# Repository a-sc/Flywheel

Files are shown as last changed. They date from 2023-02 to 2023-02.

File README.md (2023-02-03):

# Exploring flywheel energy storage with a DIY prototype

This repository contains design files and documentation for a DIY flywheel
energy storage system. It is part of my
[maturité](https://en.wikipedia.org/wiki/Matura) project on mechanical
batteries. If you want to know more about it, visit the
[website](https://a-sc.github.io/Flywheel), which is automatically generated
from the contents of the `docs` folder.

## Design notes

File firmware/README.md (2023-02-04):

# Firmware for the NUCLEO-F401RE board

The code in this directory is graciously provided by Tomasz Włostowski. He
developed it in the context of another flywheel project (based on a brushless DC
motor he scraped off a hard drive). I adapted it slightly to work on my
home-made motor, notably adjusting the proportional gain in the PI controller
and working on the sequencing of the phases to be able to turn my flywheel both
clockwise and anticlockwise. In any case, the heavy lifting was done by Tom, so
kudos to him.

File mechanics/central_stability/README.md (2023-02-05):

# 3D models used for centering of the flywheel

Here are the three 3D models used to build the centering system of the flywheel. The adapter plate is inserted into where the head of the tripod originally was, and fixed in place with the nut. Then, magnets are aligned from the bottom plate to the top plate using a screw and a spacer, as well as a nut to close it. If you want to know more about it, visit the [website](https://a-sc.github.io/Flywheel).

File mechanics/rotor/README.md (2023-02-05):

# 3D model used for rotor

The rotor consists of this 3D model printed twice and stuck together with superglue. If you want to know more about it, visit the [website](https://a-sc.github.io/Flywheel).

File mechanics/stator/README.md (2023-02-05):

# 3D models used for the stator

There are 3 coils in this stator, each made up of one 3D printed coil plate and coil shaft. These two pieces are inserted together without adhesive, and the coil is spun around the shaft by hand until the wire reaches the edge of the plate. The central part of the stator is used to provide support for the point of the rod. It is designed to fit right into the middle of the stator body, which has two sets of 3 towers equidistant to the center. The closer towers are where the hall sensors are placed, whilst the furthest towers house the coils. If you want to know more about it, visit the [website](https://a-sc.github.io/Flywheel).

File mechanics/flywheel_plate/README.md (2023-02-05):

# Flywheel plate mechanics

The flywheel plate design I am using is an earlier version of the one contained
in this directory, unfortunately not available anymore because it was done
before the design went into version control. The original author of the design
is Tomasz Włostowski, and he not only allowed me to post the files here but also
gave me a prototype of the plate made with his CNC machine. 

Although not a PCB, the mechanical design is actually a
[KiCad](https://www.kicad.org/) project, using only the PCB layout part of the
tool (i.e. no schematics). You will need KiCad 7 or later to open it. If you are
curious about its shape but not enough to install KiCad, here it is for your
viewing pleasure:

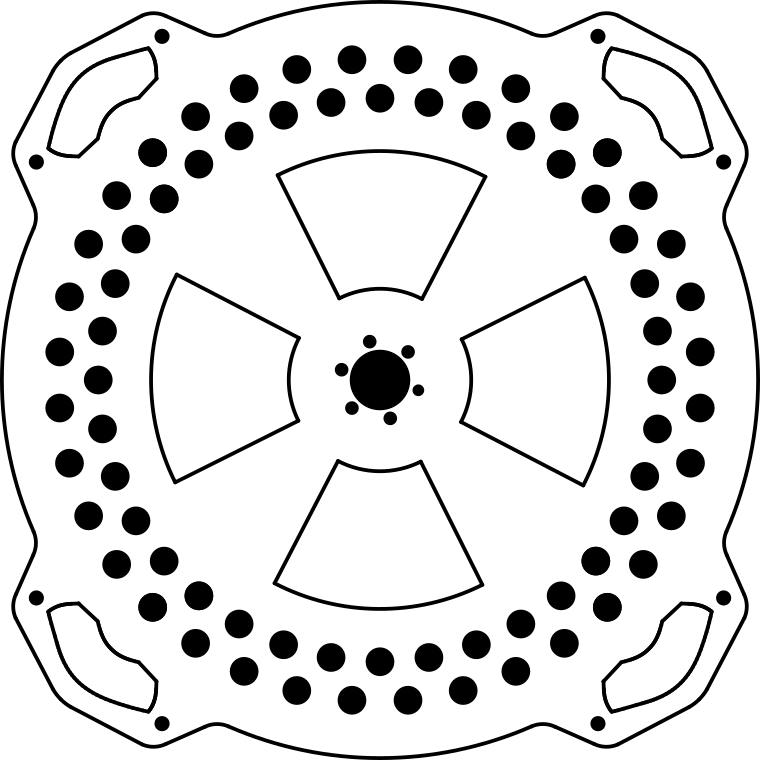
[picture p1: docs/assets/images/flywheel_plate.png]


The holes in the periphery allow increasing the moment of inertia (and hence the
stored energy for a given rotational speed) by adding nuts and bolts all around
the flywheel.

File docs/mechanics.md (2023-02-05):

---
layout: page
title: Mechanics
permalink: /mechanics/
---

* Dummy list
{:toc}

## Key concepts

The project is built around a [Manfrotto compact action tripod](https://www.manfrotto.com/us-en/compact-action-aluminium-tripod-with-hybrid-head-black-mkcompactacn-bk/) that will be used as the support for the rest of the build. The head of the tripod is removed, and an m8 threaded stainless steel rod around 450mm long is passed through the hole in the middle of the tripod. In terms of magnets, two different kinds are used: 9 [more powerful, larger magnets](https://www.magnetiques.fr/magnetique,aimant-brut-torique-19-1mm-x-9-5mm-x-6-4mm.html) and 32 [smaller and less powerful kind.](https://www.magnetiques.fr/magnetique,aimant-brut-torique-10mm-x-5mm-x-5mm.html) Both are neodymium ring magnets.

The flywheel rod is vertical. Its weight is supported by a sharpened point end, and its alignment is ensured by a magnetic centering system. The rotor is attached to the rod, towards the bottom, and the stator is on the ground directly below the rod. The flywheel is a few centimeters above the rotor.

Starting from the bottom, the project needs a moveable flat surface to facilitate alignment of different parts of the flywheel. In this case, I used a [circular wooden plate](https://www.amazon.fr/Planche-d%C3%A9couper-ronde-circulaire-double/dp/B07V1NTN4Q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), but any flat surface of similar dimensions works. The tripod will be placed on top of this surface in a fully opened position.

## Stator

On top of the base goes the stator. It is almost entirely 3D printed, and all the 3D models can be found [here](https://github.com/a-sc/Flywheel/tree/main/mechanics/stator). A [large m8 stainless steel washer](https://www.amazon.fr/Rondelles-Carrosserie-Inoxydable-Carrossier-ext%C3%A9rieur/dp/B0B6BS663W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) with an outer diameter of anywhere from 25-40mm is stuck to the bottom of the "Stator central part" model.

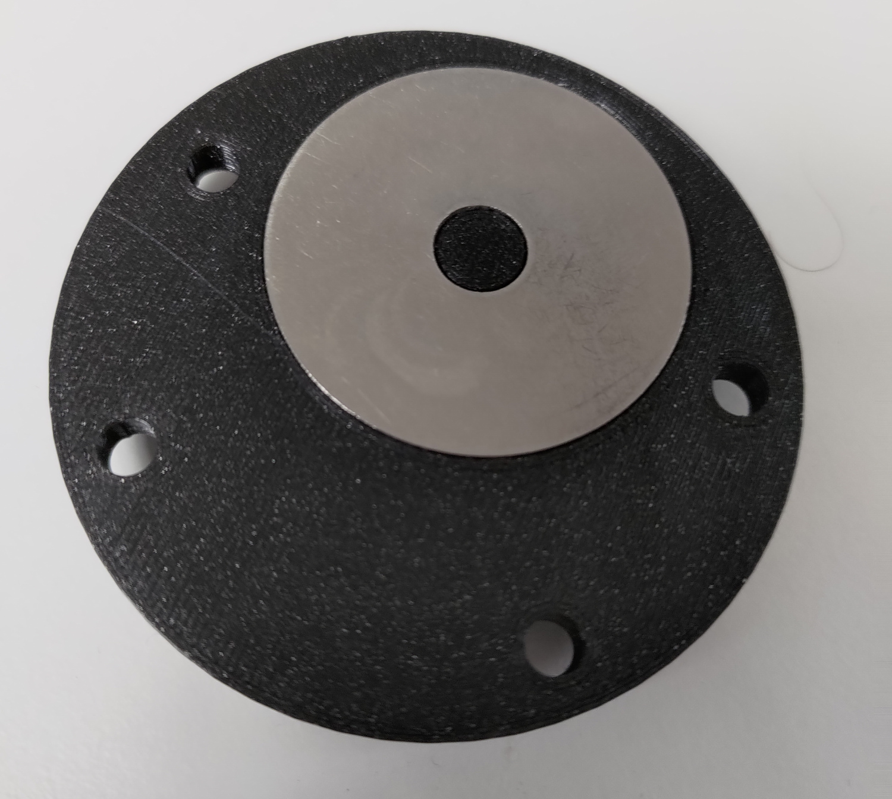
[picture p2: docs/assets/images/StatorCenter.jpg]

*Underside of the stator central part*

This is where the point of the rod will spin. This part is placed in the middle of the wooden plate, and around it goes the "Stator body".

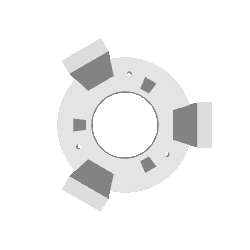
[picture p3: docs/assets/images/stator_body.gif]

*The stator body 3D model*

This part consists of 2 sets of 3 towers equidistant from the center. The 3 hall sensors are placed on the smaller towers of the stator body. 3 coils are made using the "Coil plate" and "Coil shaft" parts. This is done by inserting these two parts together without using adhesive, and wrapping 0.25mm diameter copper wire around the coil shaft until the wire comes up to the edge of the coil plate. To finish the coils, I recommend adding epoxy to the wire to stop it from moving. These 3 coils are then attached to the 3 taller towers of the stator's body. For sticking both the coils and the hall sensors to the stator's body, I used double sided tape as this gave me the most flexibility, but any adhesive works.

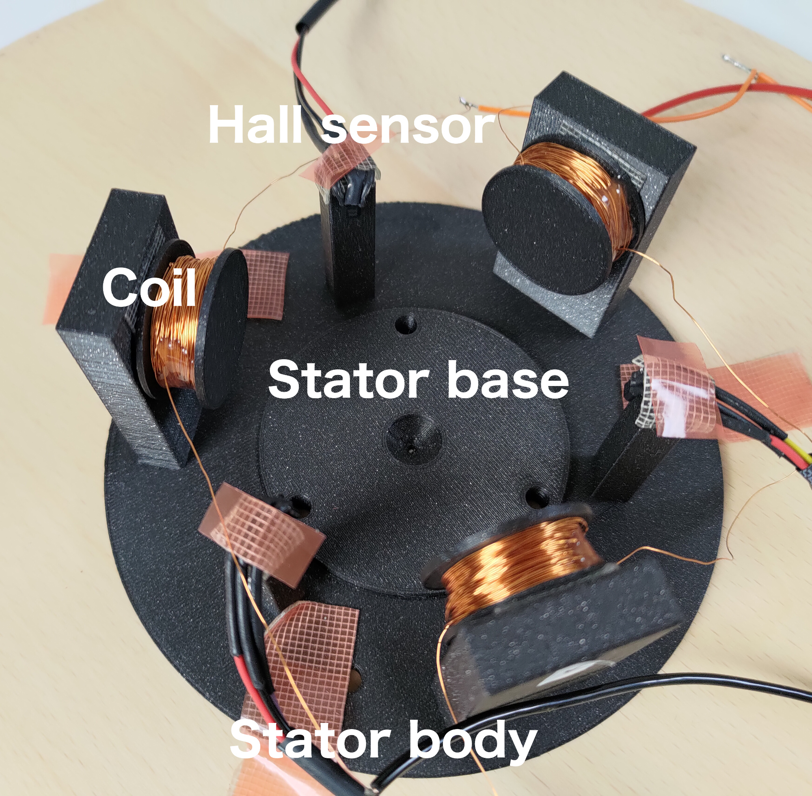
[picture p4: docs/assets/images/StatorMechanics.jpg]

*Fully assembled stator*

## Rotor and flywheel

On the rod, at the same level as the stator, is the rotor. The 3D model can be found [here](https://github.com/a-sc/Flywheel/tree/main/mechanics/rotor). The 3D model is only half of the rotor, so it has to be printed twice and stuck together with something like superglue. 

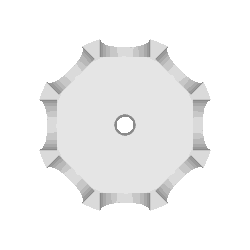
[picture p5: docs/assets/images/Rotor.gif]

*The rotor 3D model*

The rotor has 8 holes in which to put magnets. The more powerful magnets are used, and have to be placed in alternating polarities (north/south/north/south).

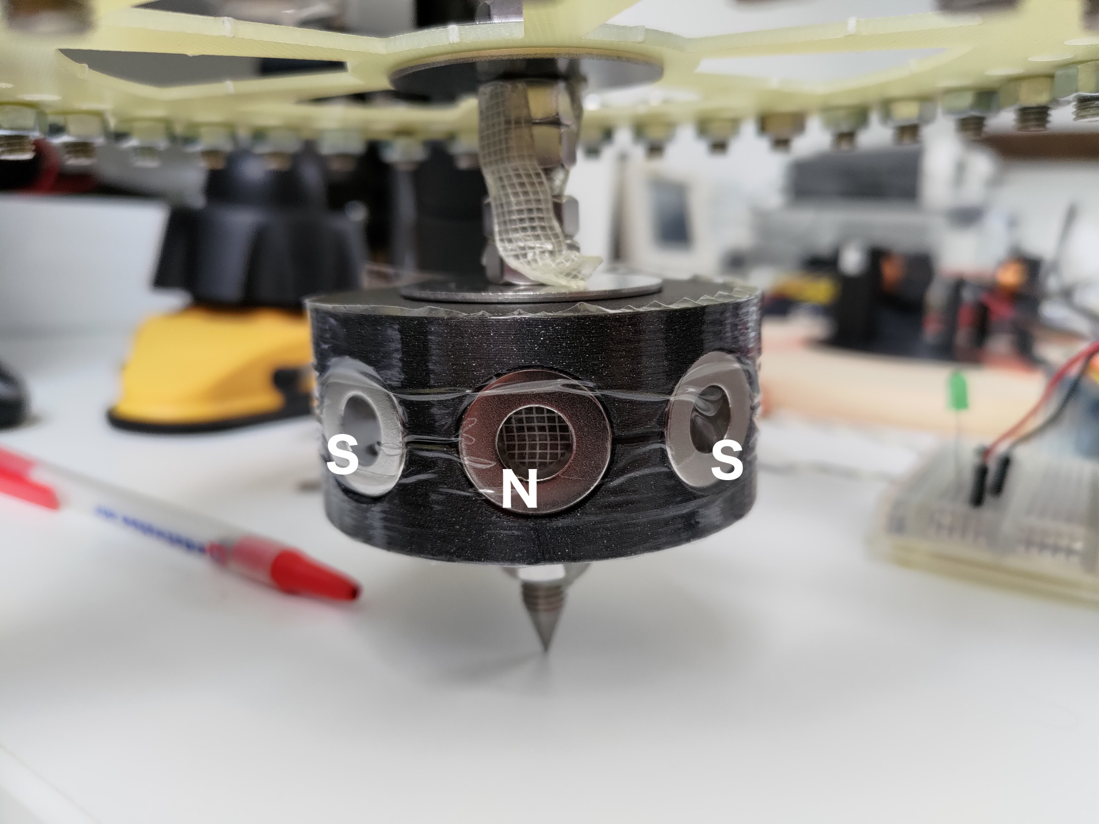
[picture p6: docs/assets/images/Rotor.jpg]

*Rotor on the threaded rod*

The flywheel that I used is a [relatively thin fiberglass disc with a radius of around 10cm](https://github.com/a-sc/Flywheel/tree/main/mechanics/flywheel_plate) and is placed slightly above the rotor. Screws are added around the outside of the flywheel to increase the moment of inertia, and the flywheel is inserted into the steel tube and fixed in place with nuts. 

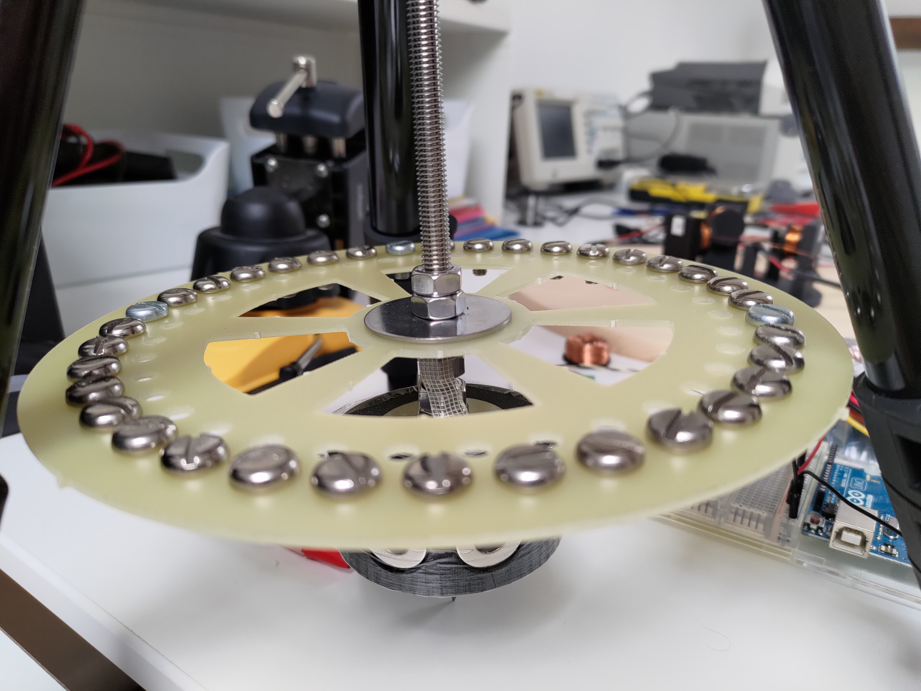
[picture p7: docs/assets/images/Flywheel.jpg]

*The flywheel I used*

In reality, any homogenous disc that fits the m8 threaded rod more or less well can be used. It does, however, need to fit inside of the tripod legs, so the diameter cannot be too large.

## Threaded rod

The threaded rod serves a few purposes: firstly, it aligns the different parts of the build vertically thanks to nuts. It also supports the weight of the build. In order for the rod to have as little friction as possible, its end has to be sharpened to a point. There are two ways to do this: one is to glue a nut to a screw and thread the nut into the end, and the other is to machine the end of the rod into a sharp point. This point is then placed on the metal washer glued to the "Stator central part", since metal on metal leads to very minimal friction. I first used the method with the screw, and the stability was satisfactory but not perfect. I later machined the end of the rod into a sharp point and there is no longer any wobbling.

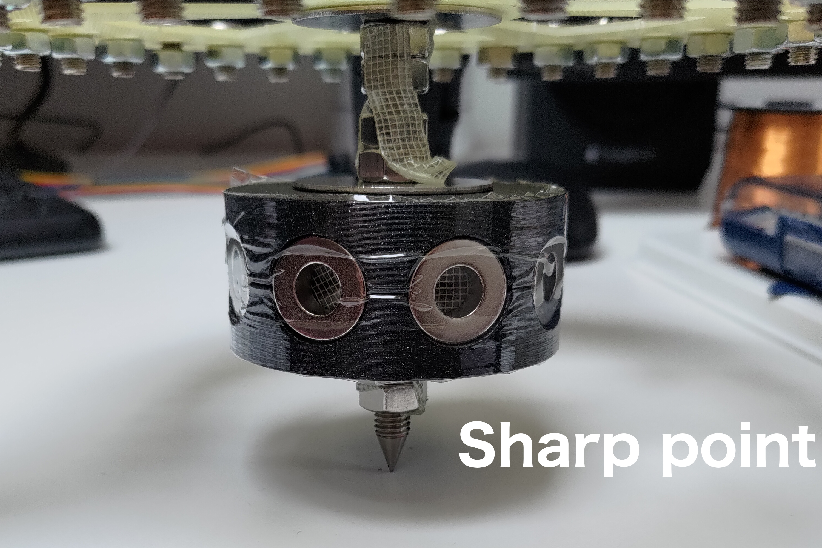
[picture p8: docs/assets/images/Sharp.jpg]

*Machined sharp point*

The third and last purpose of the rod is to align all the components horizontally, such that they are always perfectly perpendicular to the floor. The 3D models used to achieve horizontal stability can be found [here](https://github.com/a-sc/Flywheel/tree/main/mechanics/central_stability). The "tripod adapter" is inserted into the hole where the tripod head originally was, and it is held in place with the "nut tripod" object. 8 M4 stainless steel bolts are inserted into the outer holes of the "tripod adapter" from the bottom. Into each of these bolts goes a "spacer magnet" piece along with 4 small magnets. All of the magnets have to be aligned in the same direction. The end of the 8 bolts are entered into the "top plate" and fixed in place with nuts.

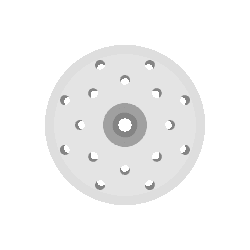
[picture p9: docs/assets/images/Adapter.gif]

*The tripod adapter 3D model*

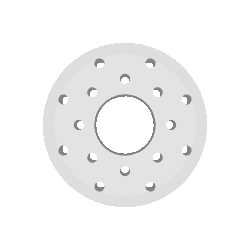
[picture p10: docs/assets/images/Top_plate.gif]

*The top plate 3D model* 

A large magnet is then added to the threaded rod in the same direction as the small magnets. Its vertical positioning should be such that it is inside the cylinder created by the smaller magnets, and slightly below the middle of the cylinder so that the vertical force is slightly downwards.

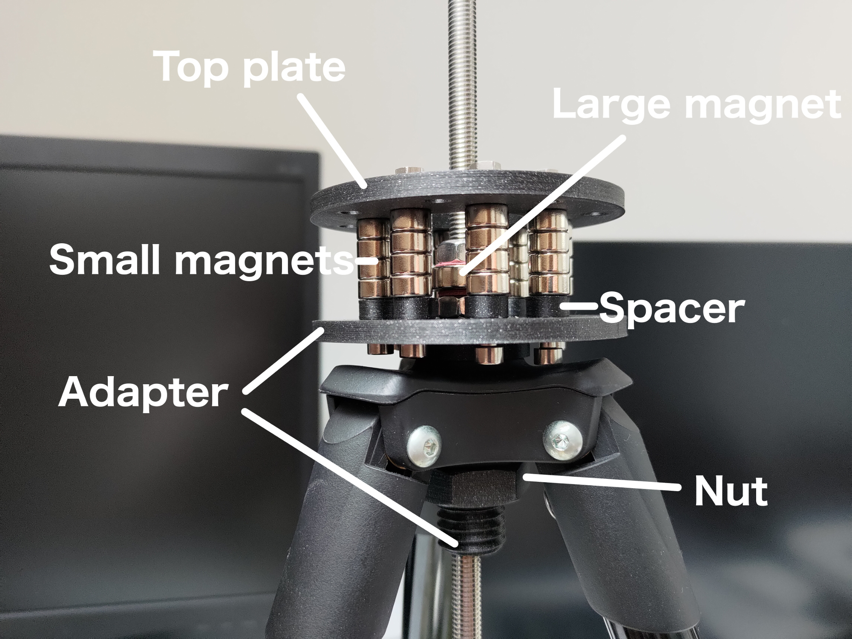
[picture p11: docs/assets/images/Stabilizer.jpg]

*Stabilizing complex*

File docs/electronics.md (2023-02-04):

---
layout: page
title: Electronics
permalink: /electronics/
---

The control of the home-made motor is pretty much like the control of any
brushless DC motor (BLDC). The main hardware components on the electronics side
are a [NUCLEO-F401RE](https://www.st.com/en/evaluation-tools/nucleo-f401re.html)
development board from ST, a [motor control
shield](https://www.infineon.com/cms/en/product/evaluation-boards/bldc-shield_ifx007t/)
by Infineon and a basic comparator circuit I put together to interface to the
Hall sensors.

* Dummy list
{:toc}

## STM32 Nucleo-64 development board

I selected this board because I could easily get hold of [BLDC control
code](https://github.com/a-sc/Flywheel/tree/main/firmware) for it. It features
an [STM32F401RE
MCU](https://www.st.com/en/microcontrollers-microprocessors/stm32f401re.html)
with 512 Kbytes of Flash memory and an 84 MHz CPU. The MCU contains all the
peripherals I need. In particular, a powerful set of timers to send pulse width
modulation (PWM) signals to the coils of the motor and measure its speed, plus
external general-purpose input/output (GPIO) pins I use to read Hall sensor
signals and have them produce interrupts.

## IFX007T motor shield

This PCB features three
[IFX007T](https://www.infineon.com/cms/en/product/power/motor-control-ics/brushed-dc-motor-driver-ics/single-half-bridge-ics/ifx007t/)
half-bridges. A half-bridge is half of what you need to make an
[H-bridge](https://en.wikipedia.org/wiki/H-bridge), which is what is typically
used to control motors. In essence, a half-bridge is made of two MOSFET
transistors connected in series. In my case, I connect the higher one to the
supply voltage (9V most of the time) and the lower one to ground. The output of
the half-bridge is the mid-point connection between the MOSFETs, so by
controlling them with the STM32 CPU I can connect the output either to ground or
to 9V.

During operation, I can drive a variable amount of current through a coil by
sending a PWM signal to the higher transistor of the corresponding H-bridge and
connecting the lower transistor (of the other half-bridge in the H-bridge) to
ground. The duty cycle of the PWM signal sets the average current through the
coil. The sense of the current depends on which half-bridge is used for,
respectively, PWM and ground, so can be easily changed by the MCU. See the
[firmware description](firmware.md) for more details.

## Interfacing with the Hall sensors

I use the [AH49E](https://www.diodes.com/part/view/AH49E/) Linear Hall-effect IC
from Diodes Incorporated for sensing the instantaneous position of the motor.
This is needed by the control firmware. The chips are conveniently available in a
TO-92S package which allowed me to solder their pins directly to flying wires and
keep full freedom in their physical placement. There are three Hall sensors in
the motor, interleaved at regular intervals with the three windings in the
stator. This means an angular separation of 120° between Hall sensors and 60°
between any Hall sensor and its closest coil either side.

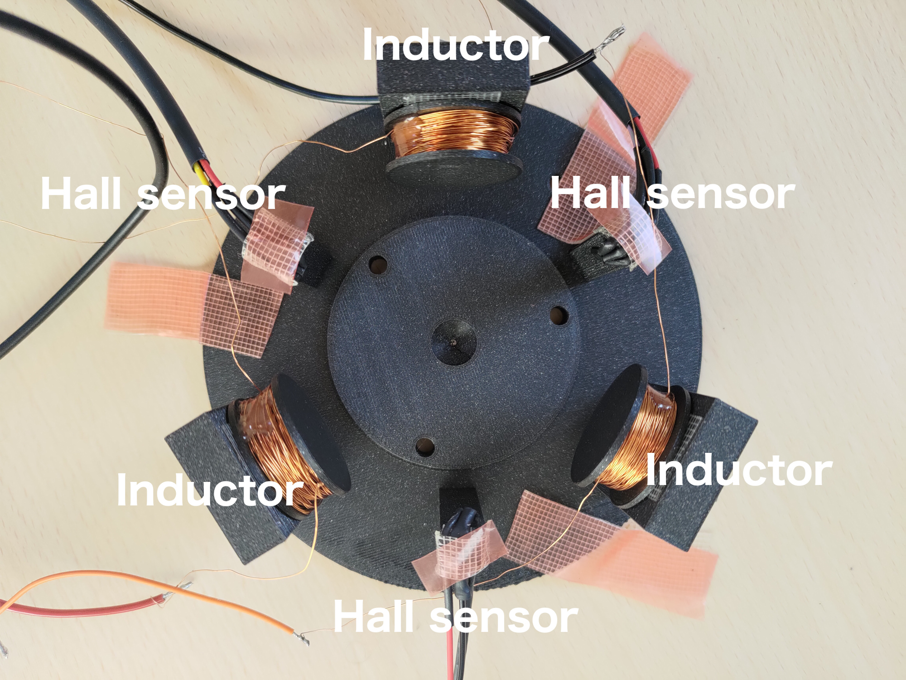
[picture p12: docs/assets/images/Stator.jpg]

*A close-up view of the placement of the Hall sensors in the stator*

The orientation of the Hall sensors is chosen to produce a negative-going signal
whenever the north pole of a permanent magnet in the rotor goes past them. The
output of the Hall sensor sits around half-way between ground and the positive
supply when not exposed to any field (the Earth field is much weaker than the
one produced by the magnets). In order to get a proper 0V or 3.3V signal I can
send to the MCU, I condition the signals coming from the sensors using a simple
LM339 comparator with a bit of hysteresis.

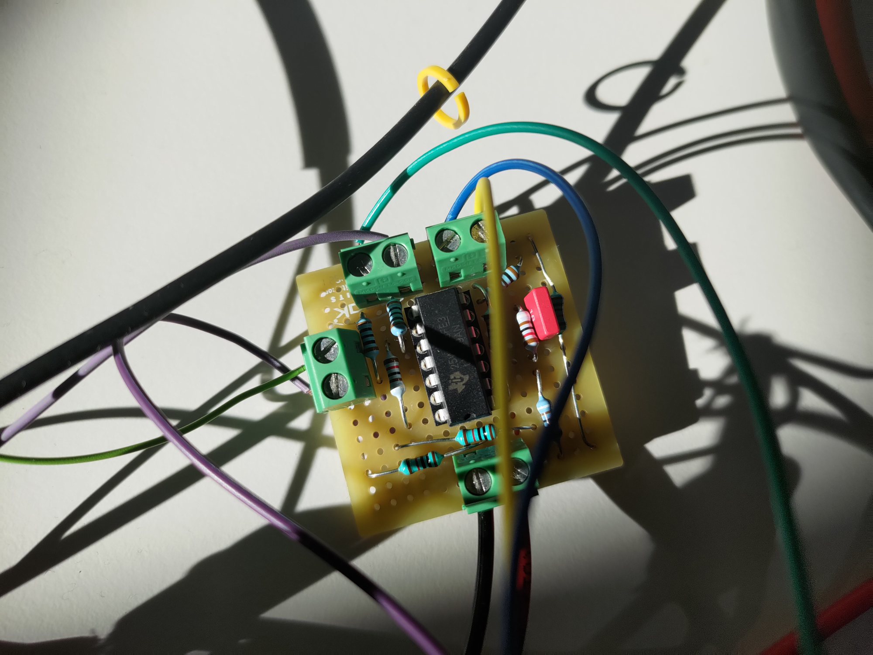
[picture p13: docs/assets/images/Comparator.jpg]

*Picture of the comparator circuit (Todo: post full schematics)*

This short video shows the signals I get in the oscilloscope as I turn the rotor
manually, making each of the Hall sensors see alternate north and south poles:

<iframe width="560" height="315" src="https://www.youtube.com/embed/Yc3aZQofmLY" title="YouTube video player" frameborder="0" allow="accelerometer; autoplay; clipboard-write; encrypted-media; gyroscope; picture-in-picture; web-share" allowfullscreen></iframe>
*Testing Hall sensor output (you can see the signal stretch in time as the rotor slows down)*

## Connection tables

They say a picture is sometimes worth more than a thousand words. Well, not in
this case! As you can see in the picture below, it is quite hard to discern the
connections in the unholy mess of wires:

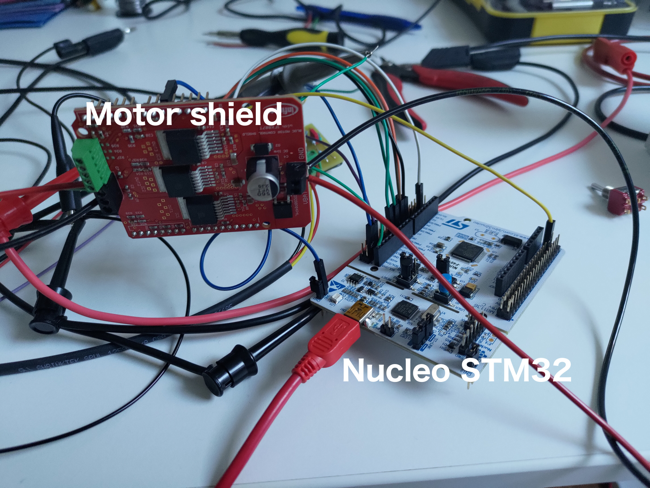
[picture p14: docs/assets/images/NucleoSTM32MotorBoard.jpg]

*The Nucleo STM32 board connected to the IFX007T motor shield*

Here's a connection table to make sense of the wiring. Please refer to the
Nucleo board [user
manual](https://www.st.com/resource/en/user_manual/um1724-stm32-nucleo64-boards-mb1136-stmicroelectronics.pdf)
and the motor shield [user manual](https://www.infineon.com/dgdl/Infineon-Motor_Control_Shield_with_IFX007T_for_Arduino-UserManual-v03_00-EN.pdf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) as appropriate, In particular, connectors in the
motor shield do not have proper designators, so you really need to look at the
user manual to make sense of the table below.

| Pin on Nucleo board | Pin on IFX007T shield |
| --- | --- |
| CN11 (any pin) | GND |
| CN10 pin 23 (PA8) | INU |
| CN10 pin 21 (PA9) | INV |
| CN10 pin 33 (PA10)  | INW | 
| CN10 pin 15 (PA7) | INHU |
| CN7  pin 34 (PB0) | INHV |
| CN10 pin 24 (PB1) | INHW |

In addition to these Nucleo-shield connections there are also three wires to
connect the Hall sensors (actually the outputs of the sensor conditioning board)
to the Nucleo board:

| Pin on Nucleo board | Sensor signal |
| --- | --- |
| CN10 pin 3 (PB8) | U |
| CN10 pin 5 (PB9) | V |
| CN10 pin 17 (PB6) | W |

Bear in mind the following naming convention for the Hall sensors: their name is
the same as that of the coil they are facing in the stator. For example, sensor
U is the one surrounded by coils V and W, and so on.

## Bill of materials

I live in France. The following is a list of items I purchased and convenient
places for me to buy them from. If you want to reproduce and build upon this
work, hopefully you can easily figure out where best to buy from in your
location.

| Item | Provider |
| --- | --- |
| Nucleo board | [Amazon](https://amzn.eu/d/cLdppPl) |
| Motor shield | [Farnell](https://fr.farnell.com/en-FR/infineon/bldcshieldifx007ttobo1/carte-de-d-mo-driver-de-moteur/dp/3051941) |
| Hall sensors | [Farnell](https://fr.farnell.com/en-FR/diodes-inc/ah49ez3-g1/hall-effect-sensor-40-to-85deg/dp/3373778)|
| Comparator | [Farnell](https://fr.farnell.com/en-FR/texas-instruments/lm339an/ic-comparator-quad-differential/dp/3118450) |

You will also need resistors, capacitors and jumper wires (female-female and
some female-male for easily probing with the oscilloscope). I trust if you have
read this far and are interested in building this, you will be able to find
these commodity items easily!

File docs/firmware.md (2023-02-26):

---
layout: page
title: Firmware
permalink: /firmware/
---

By making my home-made motor have the same electrical interfaces as any standard
off-the-shelf BLDC motor, I was able to reuse [existing
firmware](https://github.com/a-sc/Flywheel/tree/main/firmware) to control it.
The main difference with standard BLDCs is the absence of bearings, thanks to
the [magnetic alignment](mechanics.md) of the axle, and therefore the
minimization of friction. This is a key goal in energy storage flywheels. I did
have to understand the code well enough to figure out a way to spin the motor
both clockwise and counter-clockwise, and also to tune the proportional gain of
the PI controller. Below you can find a summary description of the firmware
running in the STM32 MCU.

* Dummy list
{:toc}

## Development environment

The `Makefile` uses the `arm-none-eabi-gcc` compiler for ARM chips based on
Cortex-M and Cortex-R processors. Once you have an output binary, you must use
`arm-none-eabi-objcopy` to convert its format for use by `openocd`, the tool
which flashes the binary into the STM32 through the USB interface of the Nucleo
board. In Debian, you get these tools by installing the `gcc-arm-none-eabi`,
`binutils-arm-none-eabi` and `openocd` packages. In macOS, you can `brew install
--cask gcc-arm-embedded` and `brew install open-ocd`. Then you will need a
terminal emulator program to talk with the Nucleo board during operation. I use
`GTKTerm` in Linux and `minicom` (also available as a `brew` formula) in macOS.

## Program structure

The main program does the initial setup of all relevant peripherals and then
jumps to an infinite loop which prints diagnostics data to the serial (USB) port
every 500ms. The heavy lifting is done by the interrupt handlers.

The initial setup includes:

* Setting up the three pins interfacing to the Hall sensors, and declaring the
  three of them as interrupt sources, both when they go down (falling edge) and
  when they go up (rising edge).
* Setting up the six pins interfacing to the IFX007T motor shield (three PWM and
  three inhibit pins, outputs of the STM32, inputs of the motor shield).
* Configuring the TIM1 timer (the most versatile timer in the MCU) to provide
  signals to the PWM pins, with a programmable duty cycle.
* Configuring a standard timer to count clock ticks after the rising edge of one
  of the Hall sensor signals. This is used to measure the rotating speed four
  times per turn.
  
Whenever one of the Hall sensor signals undergoes a transition, the interrupt
handler is executed:

* It samples the state of the three Hall sensor signals to find in which phase
  the motor is within the turn.
* With this information, it calls `bldc_commutate()`, the function that controls
the outputs going to the motor shield (more on this later).
* It reads the count in the general-purpose timer to estimate rotation speed.
* It feeds this information to the PI controller, so it can derive from it, and
  from past history plus the speed requested by the user, a duty cycle of the
  signals to be sent to the motor shield. 

## Driving the coils

The three coils are spaced 120° apart from one another. Each coil has one end
connected to a half-bridge and the other end connected to the other coils. A
diagram will help:

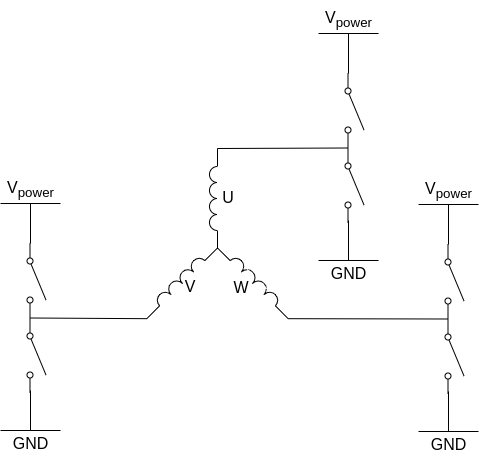
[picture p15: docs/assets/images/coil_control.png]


It is customary to label the coils U, V and W when working with BLDC motors. Now
imagine that the Hall sensor sitting between coils U and V has just signaled the
passage of a north pole in front of it. If that rotor magnet showing its north
pole is headed towards U, then we want U to attract it and V to repel it. That
means U should become a south pole and V should become a north pole. I have
connected the windings in a way that makes them become north poles when current
comes from the half-bridge. So in this particular example, the firmware must
drive a PWM signal into the upper switch (MOSFET) of the V half-bridge and close
the lower switch (i.e. connect it to GND) in the U half-bridge. Current then
flows from the V<sub>power</sub> supply through the upper switch of the V
bridge, then the V winding, U winding and out of the U winding to GND, turning
the V coil into a north pole and the U coil into a south pole as desired. The
average current will depend on the duty cycle of the PWM signal, as provided by
the PI controller.

## Proportional Integral (PI) control

In PI control, the system continuously measures the controlled variable (in this
case rotational speed) and derives an error signal from it by subtracting the
measured speed from the set point (the speed the user wants). This error signal
is then fed to the controller, which produces a duty cycle for the PWM signals.

In steady state, the error is close to zero, so if we only used proportional
control (i.e. having the duty cycle be proportional to the error) the system
would oscillate back and forth around the set point. The duty cycle would go to
zero when the speed were reached, which would make the speed go down, then the
error go up, then the duty cycle go up and so forth. By having an integral
branch in the controller, added to the proportional branch to generate the duty
cycle output, we can have a non-zero output even when the system is locked at
the right speed, which is exactly what we want.

Both the proportional and the integral branch of the controller have their own
gains. These are multiplicative constants, customarily named k<sub>p</sub> and
k<sub>i</sub>, which the user can set to fine-tune the dynamics of the feedback
system.

I mention all this because one of the slight tweaks I had to do on the firmware
side was to adjust the value of k<sub>p</sub>. In the internal integer
representation of the error in the PI controller, one rpm corresponds to 68
counts. If I wanted the proportional part to provide a correction signal when
the error was 1 rpm, then I had to push k<sub>p</sub> to a value of 200, so its
contribution would not disappear due to some scaling (right shift) done inside
the code.

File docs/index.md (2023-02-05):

---
# Feel free to add content and custom Front Matter to this file.
# To modify the layout, see https://jekyllrb.com/docs/themes/#overriding-theme-defaults

layout: home
---

Many renewable energy sources, like wind and solar, are intermittent. It is
therefore important to be able to store energy cleanly so that it can be used
when it's needed. In flywheel energy storage systems, surplus energy is stored
in the form of the (rotating) kinetic energy of a high-inertia object called a
flywheel. No chemicals are involved, which makes them very friendly to the
environment. In addition, wear out is minimal. On the down side, these systems
are difficult to transport and the stored energy is gradually lost as heat due
to the friction between the rotating part (rotor) and the static part (stator)
of the system.

This project explores flywheel energy storage systems through the development of
a prototype aimed at minimizing friction. I designed a motor with no mechanical
bearings. The contact of the rotor with the outside world is limited to the very
sharp tip of a metallic rod. The rest of the alignment is made with the help of
magnets, therefore avoiding any physical contact.

The video below gives you an idea of what the system looks like when in action.
You will find more in-depth information in the rest of the site.

<iframe width="560" height="315" src="https://www.youtube.com/embed/k8Cg9cRpWMs" title="YouTube video player" frameborder="0" allow="accelerometer; autoplay; clipboard-write; encrypted-media; gyroscope; picture-in-picture; web-share" allowfullscreen></iframe>

## Site navigation hints

* Get all stable material using the navigation bar at the top (or the drop-down
  menu if you are using a small screen).
* Get more "volatile" material in the list of posts below.
* The design files and firmware source can be found in the [github
  repo](https://github.com/a-sc/Flywheel). Ongoing work and future plans are
  documented in the [issues](https://github.com/a-sc/Flywheel/issues).

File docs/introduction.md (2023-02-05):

---
layout: page
title: Introduction
permalink: /introduction/
---

The aim of this project is to build a flywheel that will store and release electrical energy.

* first item
{:toc}

## Introduction to flywheels

The concepts used in flywheels have been around since the invention of the wheel: a flywheel is a spinning disc that stores energy through its rotation.

Modern flywheel batteries are often used in long-term energy storage solutions and are usually highly massive to optimize energy loss thanks to their high moment of inertia. To store energy, a motor is used to convert electrical energy into mechanical rotational energy through the spinning of the flywheel. In order to release energy, the motor works in reverse as a generator, slowing the rotation of the flywheel.

The flywheel is either levitated using magnetic bearings or attached to very well oiled mechanical bearings, minimizing energy losses due to friction.

## Design choices

The project is built around a Manfrotto compact action tripod that will be used as the support for the rest of the build. The head of the tripod is removed, and a threaded inox steel tube is passed through the hole in the middle of the tripod. The flywheel itself is a relatively thin fiberglass disc with a radius of around 10 cm. Screws are added around the outside of the flywheel to increase the moment of inertia, and the flywheel is inserted into the steel tube and fixed in place with nuts. 

The flywheel is therefore supported vertically. In order to support the weight of the tube, a sharp end is added at the bottom. This sharp end is placed on metal in order to minimize energy loss due to friction. Vertical alignment is ensured thanks to a circular magnet fitted into the tube. All around this magnet are repelling magnets that ensure that the tube stays perfectly vertical and does not drift from side to side.

A homemade brushless motor is used to store and extract energy from the
flywheel. It consists of a rotor and a stator which are explained in depth in
[the mechanics page](mechanics.md).

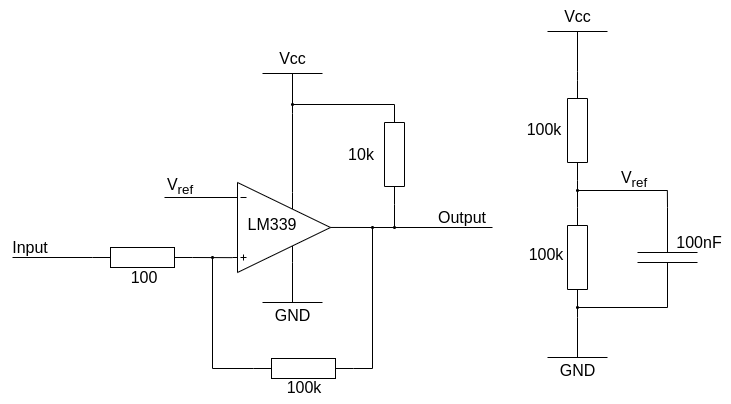
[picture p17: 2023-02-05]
docs/assets/images/comparator_with_hysteresis.png

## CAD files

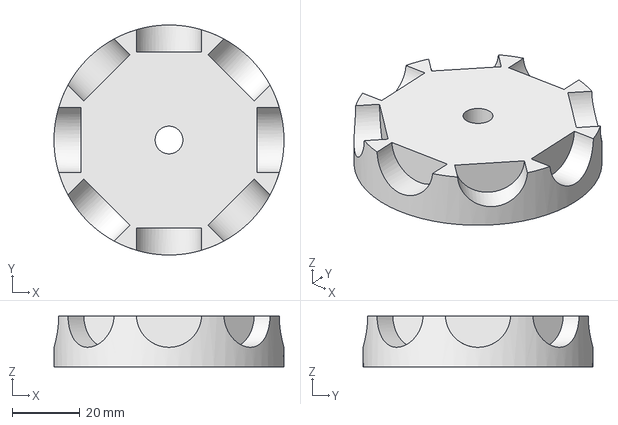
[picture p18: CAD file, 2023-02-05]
mechanics/rotor/Rotor.FCStd
68.0 x 68.0 x 15.0 mm

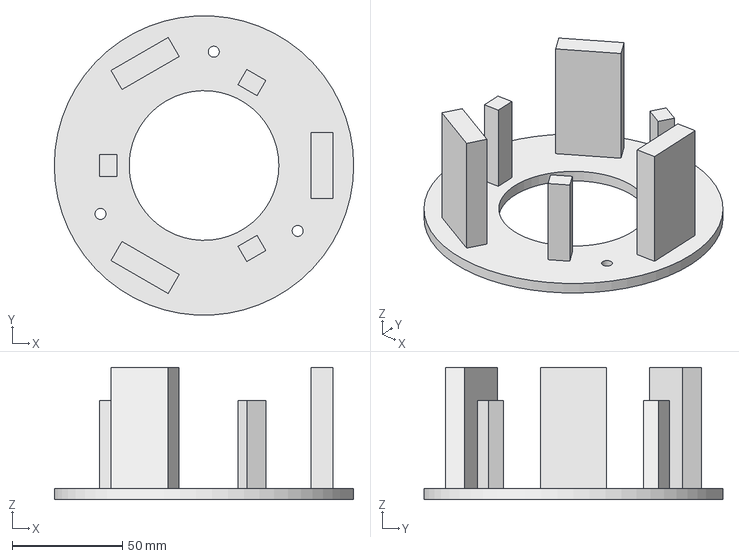
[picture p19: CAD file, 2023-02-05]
mechanics/stator/Stator_body.FCStd
136.0 x 135.8 x 60.0 mm

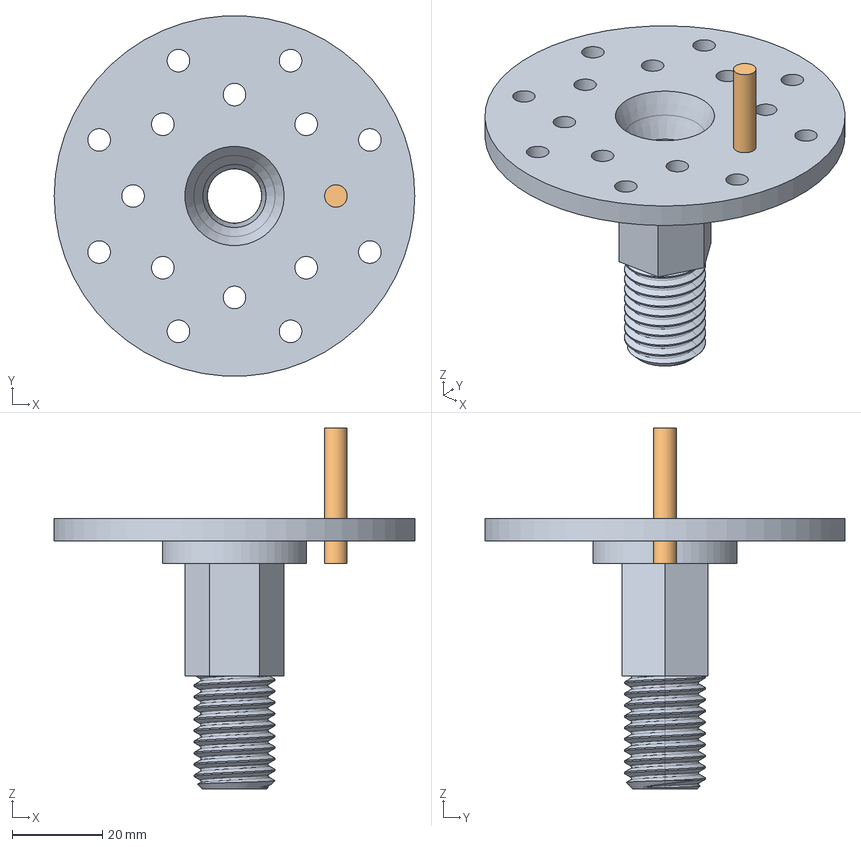
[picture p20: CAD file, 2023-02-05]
mechanics/central_stability/Tripod_adapter.FCStd
80.0 x 79.9 x 80.0 mm
Holes 1

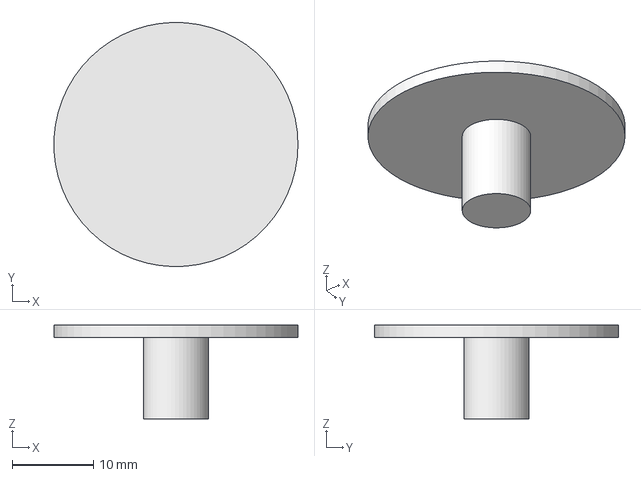
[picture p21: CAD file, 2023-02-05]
mechanics/stator/Coil_shaft.FCStd
30.0 x 30.0 x 11.5 mm

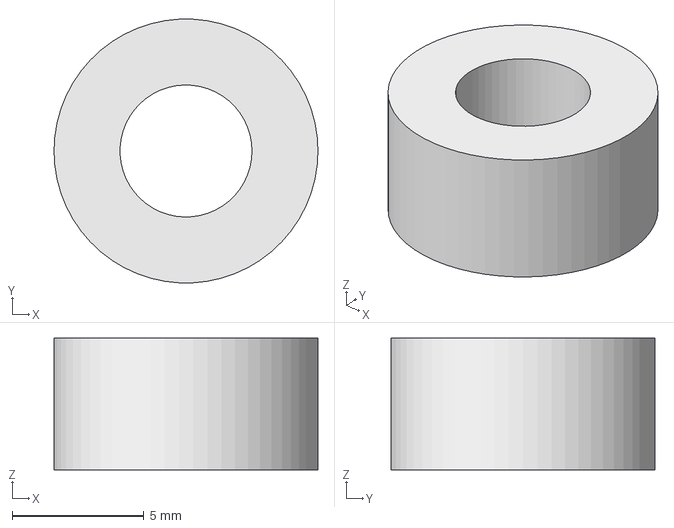
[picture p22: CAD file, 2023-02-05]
mechanics/central_stability/Spacer_magnet.FCStd
10.0 x 9.99 x 5.00 mm

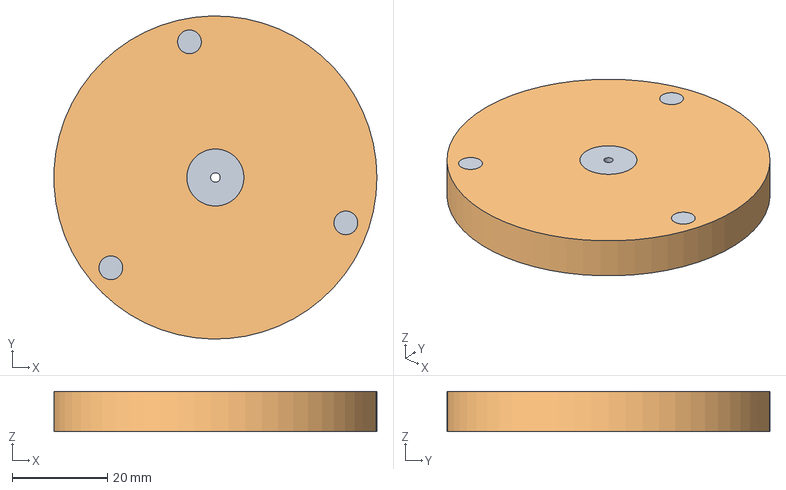
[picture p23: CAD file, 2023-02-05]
mechanics/stator/Stator_central_part.FCStd
68.0 x 68.0 x 8.50 mm

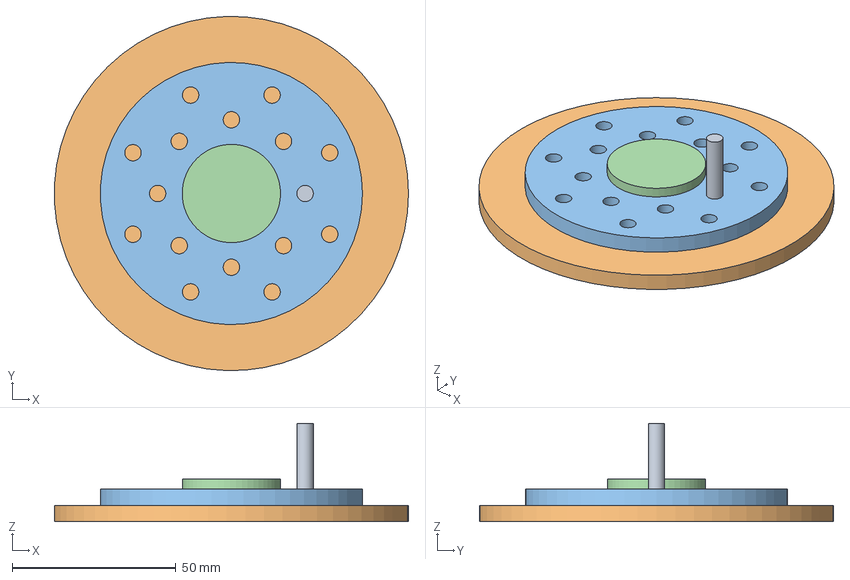
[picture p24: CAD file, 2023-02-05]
mechanics/central_stability/Top_plate.FCStd
108.0 x 108.1 x 30.0 mm
Holes 1
Plaque haut001
Hole 2

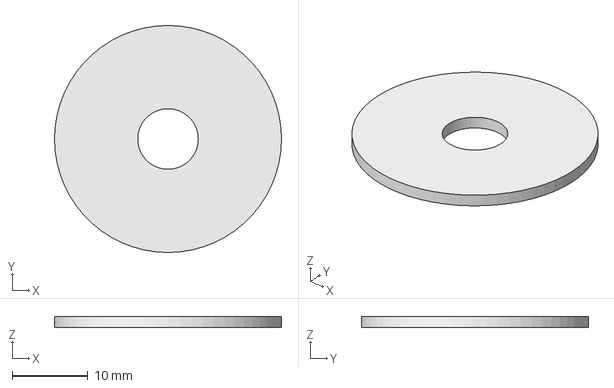
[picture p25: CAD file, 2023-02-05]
mechanics/stator/Coil_plate.FCStd
30.0 x 30.0 x 1.50 mm

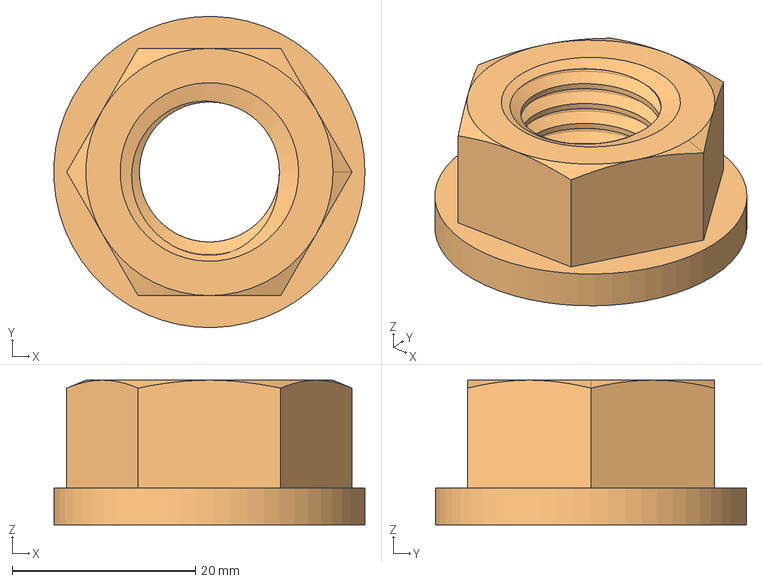
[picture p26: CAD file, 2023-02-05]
mechanics/central_stability/Nut_tripod.FCStd
34.0 x 34.0 x 15.8 mm

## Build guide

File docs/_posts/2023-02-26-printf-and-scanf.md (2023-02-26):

---
layout: post
title:  "Interactive control of the motor from a laptop"
date:   2023-02-26 21:35:00 +0100
---

As I write this, the project is at commit c9b6b35. You can use [this
link](https://github.com/a-sc/Flywheel/tree/c9b6b351d2ad0e428fc1421b7ee499edfa6beab9)
to browse the code at that particular commit, in case it changes in the future
and some of the information in this post no longer applies. The [initial
code](https://github.com/a-sc/Flywheel/tree/7137e67b5240492d49ae9100eec4e01b828223a7)
I got from Tom had the motor start immediately after power up, with a speed set
point which was hard coded. Statistics were continuously printed on the screen
of the laptop using a simplified version of `printf()`, but there was nothing
resembling `scanf()`, which would make life much simpler to make the control of
the motor more interactive.

### Using newlib-nano as C standard library

In the
[`Makefile`](https://github.com/a-sc/Flywheel/blob/c9b6b351d2ad0e428fc1421b7ee499edfa6beab9/firmware/Makefile),
option `--specs=nano.specs` is passed to the linker. This means my object code
links to newlib-nano, a space-conscious version of newlib.
[Newlib](https://sourceware.org/newlib/) is an implementation of the C standard
library intended for embedded systems. Since both `printf()` and `scanf()` live
in the standard library, I should be in business, right? Well, it's not so
simple. `printf()` needs to be told how to write in your particular setup (in
this case I want it to write to the UART) and similarly `scanf()` needs
low-level read support. Luckily, I found [this
post](https://interrupt.memfault.com/blog/boostrapping-libc-with-newlib) by
François Baldassari very clearly explaining how to add this kind of support in a
particular system. I needed to add code in
[`usart.c`](https://github.com/a-sc/Flywheel/blob/c9b6b351d2ad0e428fc1421b7ee499edfa6beab9/firmware/src/usart.c)
for 7 low-level functions: `_fstat()`, `_close()`, `_lseek()`, `_isatty()`,
`_sbrk()`, `_read()` and `_write()`. The first 4 are fairly trivial. I just
copied/pasted his code.

`_sbrk()` is used by `printf()` to dynamically allocate memory. It receives as
an argument the number of chars to allocate and internally manages a pointer to
the top of the heap, which grows every time new memory is allocated. This means
you need to know were your heap starts before you can write `_sbrk()`.

### An aside: linker scripts

In the STM32F401RE, there are 512KB of flash starting at address 0x08000000 and
96KB of RAM starting at 0x20000000. The [linker
script](https://github.com/a-sc/Flywheel/blob/c9b6b351d2ad0e428fc1421b7ee499edfa6beab9/firmware/Device/gcc.ld)
is where you tell the linker where each part of your program goes. It uses a
relatively obscure syntax, but as luck would have it, François comes again to
the rescue with another clear
[post](https://interrupt.memfault.com/blog/how-to-write-linker-scripts-for-firmware).
Space in RAM is used for the `.data` and `.bss` sections successively. The
`.data` section, starting at address 0x20000000 in my case, contains all
initialized data (i.e. variables I initialized after declaring them in the
code). The `.bss` section contains all uninitialized data, which is cleared
(i.e. set to zero) by the [startup
code](https://github.com/a-sc/Flywheel/blob/c9b6b351d2ad0e428fc1421b7ee499edfa6beab9/firmware/Device/startup_stm32f401xe.s)
written in ARM assembler. The rest of RAM is free to use. In my linker script,
the heap starts at the end of the `.bss` section and grows upwards (i.e. towards
increasing addresses) whenever new memory is dynamically allocated. The stack
starts at the end of RAM (address 0x20017FFF) and grows downwards. I don't think
there is any rock-solid way to make sure your heap and stack don't step on each
other at some point, at least not at compile time. Your compiler cannot know in
advance which paths your code will take, and how many times you will allocate
dynamic memory (on the heap) or call functions which will need space for their
arguments and automatic variables in the stack. In this particular application,
the code is relatively simple and most of the 96KB is available for heap and
stack, so we are safe.

### The intricacies of `_read()` and `_write()`

The UART code is interrupt-based. This ensures you don't overflow the UART TX
path by writing another character to it before it has finished sending the
previous one. Conversely, in the RX path, it is good to be awakened by an
interrupt every time a character is received from the serial line so that it can
be read before another incoming character overwrites the RX register.

On the read side, the UART generates an interrupt every time a character is
received (from the laptop through USB in my case). The interrupt handler,
`USART2_IRQHandler()`, reads the character and does two things with it: send it
to the TX of the UART (so the user typing in the laptop can see the character
(s)he typed) and push it to an RX FIFO. The `_read()` function just reads from
the FIFO in a busy loop until the number of characters requested by `scanf()` is
received. If a `\r` character is received, the busy waiting stops and the
function returns with the number of characters read until then.

On the write side, the UART generates an interrupt when its TX buffer is empty.
This means that, after it is enabled in the `usart_send()` routine, it will
generate an interrupt. Then, in the `USART2_IRQHandler()` function, the
character will be read from the TX FIFO and sent out to the serial line.

### Status and plans

With `printf()` and `scanf()` fully working now, I have implemented three simple
commands: `start`, `stop` and `set speed XXXX`. Next I plan to add some simple
telemetry so that I can use the data to better tune the PI controller and study
in detail the deceleration of the flywheel after external power is switched off.

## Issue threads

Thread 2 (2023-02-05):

Have more consistent starting of the motor

a-sc, 2023-02-05:
Look for literature on strategies for starting before any interrupts come from Hall sensors. Implement in firmware.

a-sc, 2023-02-15:
Much more robust already after commit 30540f63c10f7fe3bdb00f4dbb8c08e72f2c5f3d. Still some rare cases where motor needs a bit of manual help to start.

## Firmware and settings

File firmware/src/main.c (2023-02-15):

#include <stdio.h>
#include <string.h>

#include "stm32f4xx_conf.h"
#include "stm32f4xx.h"

#include "usart.h"
#include "common.h"
#include "bldc.h"


void clock_info()
{
    RCC_ClocksTypeDef rcc;
    RCC_GetClocksFreq(&rcc);

    printf("\r\nClock information:\r\n");
    printf("SWS: %d\r\n", rcc.sws);
    printf("SYSCLK: %d Hz\r\n", rcc.SYSCLK_Frequency);
    printf("AHB: %d Hz\r\n", rcc.HCLK_Frequency);
    printf("APB1: %d Hz\r\n", rcc.PCLK1_Frequency);
    printf("APB2: %d Hz\r\n", rcc.PCLK2_Frequency);
}


int main(void)
{
    SystemInit();
  
    SystemCoreClockUpdate();
    SysTick_Config(SystemCoreClock / 1000);

    GPIO_InitTypeDef  GPIO_InitStructure;

    RCC_AHB1PeriphClockCmd(RCC_AHB1Periph_GPIOA, ENABLE);
    RCC_AHB1PeriphClockCmd(RCC_AHB1Periph_GPIOB, ENABLE);
    RCC_AHB1PeriphClockCmd(RCC_AHB1Periph_GPIOC, ENABLE);
    RCC_AHB1PeriphClockCmd(RCC_AHB1Periph_GPIOD, ENABLE);

    GPIO_InitStructure.GPIO_Pin = GPIO_Pin_5;
    GPIO_InitStructure.GPIO_Mode = GPIO_Mode_OUT;
    GPIO_InitStructure.GPIO_OType = GPIO_OType_PP;
    GPIO_InitStructure.GPIO_PuPd = GPIO_PuPd_NOPULL;
    GPIO_InitStructure.GPIO_Speed = GPIO_Fast_Speed;
    GPIO_Init(GPIOA, &GPIO_InitStructure);

    NVIC_PriorityGroupConfig(NVIC_PriorityGroup_4);

    usart_init();

    clock_info();
   
struct bldc_state bldc;
char command[100], arg1[100];
int speed_sp = 750;

 for(;;){
   printf("\r\nEnter command: ");
   scanf("%s", command);
   if (!strcmp(command, "start")) {
     bldc_init(&bldc);
     bldc.speed_setpoint = (speed_sp << 12)/60; 
     bldc.reverse_hall_phase = 1;
     bldc.hall_phase_advance = 1;
     delay(100);
     bldc_start(&bldc);
   }
   else if (!strcmp(command, "stop"))
     bldc_init(&bldc);
   else if (!strcmp(command, "set")) {
       scanf("%s %d", arg1, &speed_sp);
       if (!strcmp(arg1, "speed")) {
	 printf("\r\nRequested speed: %d rpm\r\n", speed_sp);
	 bldc.speed_setpoint = (speed_sp << 12) / 60;
       } else
	 printf("\r\nInvalid command\r\n");
   }
   else 
     printf("\r\nInvalid command\r\n");
 }

    return 0;
}

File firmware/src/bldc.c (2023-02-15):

#include <stdio.h>
#include <math.h>
#include <string.h>

#include "stm32f4xx.h"
#include "stm32f4xx_gpio.h"
#include "stm32f4xx_rcc.h"
#include "stm32f4xx_usart.h"
#include "stm32f4xx_adc.h"
#include "stm32f4xx_dma.h"
#include "stm32f4xx_tim.h"
#include "misc.h"

#include "bldc.h"
#include "dsp_math.h"
#include "common.h"

#define USE_TIM10_IRQ 0

static volatile struct bldc_state *g_bldc = NULL;

#if USE_TIM10_IRQ
// currently unused
void TIM1_UP_TIM10_IRQHandler(void)
{
	if (TIM_GetITStatus(TIM1, TIM_IT_Update) != RESET)
	{
		TIM_ClearITPendingBit(TIM1, TIM_IT_Update);
	}
}
#endif

static inline int bldc_read_hall_state(volatile struct bldc_state *dev)
{
	uint32_t gpio = GPIO_ReadInputData(GPIOB);

	int hall_pos = (gpio & GPIO_Pin_6) ? 1 : 0;
	hall_pos |= (gpio & GPIO_Pin_8) ? 2 : 0;
	hall_pos |= (gpio & GPIO_Pin_9) ? 4 : 0;

	return hall_pos;
}

void bldc_hall_update_position(volatile struct bldc_state *dev, int hall_pos)
{
	switch (hall_pos)
	{
	case 0b101:
		dev->hall_phase = 1;
		break;
	case 0b001:
		dev->hall_phase = 2;
		break;
	case 0b011:
		dev->hall_phase = 3; 
		break;
	case 0b010:
		dev->hall_phase = 4; 
		break;
	case 0b110:
		dev->hall_phase = 5;
		break;
	case 0b100:
		dev->hall_phase = 0;
		break;
	default:
		dev->hall_phase = 0; 
		break;
	}

	if (dev->hall_phase_d >= 0)
	{
		if (((dev->hall_phase_d + 1) % 6) != dev->hall_phase
		&& ((dev->hall_phase_d + 5) % 6) != dev->hall_phase )
		{
			dev->hall_step_missed++;
		}
	}

	dev->hall_phase_d = dev->hall_phase;
}

void bldc_pwm_init(struct bldc_state *dev)
{
	GPIO_InitTypeDef gpio_s;
	TIM_TimeBaseInitTypeDef tim_base_s;
	TIM_OCInitTypeDef tim_oc_s;
	TIM_BDTRInitTypeDef tim_bdtr_s;

	dev->pwm_period = BLDC_DEFAULT_CHOPPER_PERIOD;
	dev->pwm_duty = 3 * BLDC_DEFAULT_CHOPPER_PERIOD / 4;

	RCC_AHB1PeriphClockCmd(RCC_AHB1Periph_GPIOA, ENABLE);
	RCC_AHB1PeriphClockCmd(RCC_AHB1Periph_GPIOB, ENABLE);
	RCC_AHB1PeriphClockCmd(RCC_AHB1Periph_GPIOC, ENABLE);
	RCC_AHB1PeriphClockCmd(RCC_AHB1Periph_GPIOD, ENABLE);
	RCC_AHB1PeriphClockCmd(RCC_AHB1Periph_GPIOE, ENABLE);

	// RCC_APB2PeriphClockCmd(RCC_APB2Periph_GPIOA | RCC_APB2Periph_GPIOB, ENABLE);

	/* nucleo-f401RE PWM pin mapping:
	TIM1_CH1 = PA8 = CN10-23 = AF01
	//TIM1_CH1N = PA7 = CN10-15= AF01
	TIM1_CH2 = PA9 = CN10-21= AF01
	//TIM1_CH2N = PB0 = CN7-34= AF01
	TIM1_CH3 = PA10 = CN10-33= AF01
	//TIM1_CH3N = PB1 = CN10-24= AF01
	*/

	// initialize Tim1 PWM outputs
	gpio_s.GPIO_Pin = GPIO_Pin_8 | GPIO_Pin_9 | GPIO_Pin_10;
	gpio_s.GPIO_Speed = GPIO_Speed_50MHz;
	gpio_s.GPIO_Mode = GPIO_Mode_AF;
	gpio_s.GPIO_OType = GPIO_OType_PP;
	GPIO_Init(GPIOA, &gpio_s);

	gpio_s.GPIO_Pin = GPIO_Pin_7;
	gpio_s.GPIO_Speed = GPIO_Speed_50MHz;
	gpio_s.GPIO_Mode = GPIO_Mode_OUT;
	gpio_s.GPIO_OType = GPIO_OType_PP;
	GPIO_Init(GPIOA, &gpio_s);

	gpio_s.GPIO_Pin = GPIO_Pin_0 | GPIO_Pin_1;
	gpio_s.GPIO_Speed = GPIO_Speed_50MHz;
	gpio_s.GPIO_Mode = GPIO_Mode_OUT;
	gpio_s.GPIO_OType = GPIO_OType_PP;
	GPIO_Init(GPIOB, &gpio_s);

	//	GPIO_PinAFConfig( GPIOA, GPIO_PinSource7, GPIO_AF_TIM1 );
	GPIO_PinAFConfig(GPIOA, GPIO_PinSource8, GPIO_AF_TIM1);
	GPIO_PinAFConfig(GPIOA, GPIO_PinSource9, GPIO_AF_TIM1);
	GPIO_PinAFConfig(GPIOA, GPIO_PinSource10, GPIO_AF_TIM1);
	//	GPIO_PinAFConfig( GPIOB, GPIO_PinSource0, GPIO_AF_TIM1 );
	//	GPIO_PinAFConfig( GPIOB, GPIO_PinSource1, GPIO_AF_TIM1 );

	RCC_APB2PeriphClockCmd(RCC_APB2Periph_TIM1, ENABLE);
	// Time Base configuration
	tim_base_s.TIM_Prescaler = 10;
	tim_base_s.TIM_CounterMode = TIM_CounterMode_Up;
	tim_base_s.TIM_Period = dev->pwm_period;
	tim_base_s.TIM_ClockDivision = 0;
	tim_base_s.TIM_RepetitionCounter = 0;
	TIM_TimeBaseInit(TIM1, &tim_base_s);

	// Channel 1, 2, 3 – set to PWM mode - all 6 outputs
	tim_oc_s.TIM_OCMode = TIM_OCMode_PWM2;
	tim_oc_s.TIM_OutputState = TIM_OutputState_Enable;
	tim_oc_s.TIM_OutputNState = TIM_OutputNState_Disable;

	tim_oc_s.TIM_OCPolarity = TIM_OCPolarity_Low;
	tim_oc_s.TIM_OCNPolarity = TIM_OCNPolarity_Low;
	tim_oc_s.TIM_OCIdleState = TIM_OCIdleState_Reset;
	tim_oc_s.TIM_OCNIdleState = TIM_OCNIdleState_Reset;

	tim_oc_s.TIM_Pulse = 0;
	TIM_OC1Init(TIM1, &tim_oc_s);
	tim_oc_s.TIM_Pulse = 0;
	TIM_OC2Init(TIM1, &tim_oc_s);
	tim_oc_s.TIM_Pulse = 0;
	TIM_OC3Init(TIM1, &tim_oc_s);

	// Update CCRx only on update event (now it's underflow)
	TIM_OC1PreloadConfig(TIM1, TIM_OCPreload_Disable);
	TIM_OC2PreloadConfig(TIM1, TIM_OCPreload_Disable);
	TIM_OC3PreloadConfig(TIM1, TIM_OCPreload_Disable);

	tim_bdtr_s.TIM_OSSRState = TIM_OSSRState_Disable;
	tim_bdtr_s.TIM_OSSIState = TIM_OSSIState_Disable;
	tim_bdtr_s.TIM_LOCKLevel = TIM_LOCKLevel_OFF;
	// DeadTime[ns] = value * (1/SystemCoreFreq) (on 72MHz: 7 is 98ns)
	tim_bdtr_s.TIM_DeadTime = 0;
	tim_bdtr_s.TIM_AutomaticOutput = TIM_AutomaticOutput_Disable;
	// Break functionality (overload input)
	// tim_bdtr_s.TIM_Break = TIM_Break_Enable;
	// tim_bdtr_s.TIM_BreakPolarity = TIM_BreakPolarity_Low;
	tim_bdtr_s.TIM_Break = TIM_Break_Disable;
	tim_bdtr_s.TIM_BreakPolarity = TIM_BreakPolarity_High;
	TIM_BDTRConfig(TIM1, &tim_bdtr_s);
	TIM_ClearFlag(TIM1, TIM_IT_Update);
	TIM_ITConfig(TIM1, TIM_IT_Update, ENABLE);

	// TIM_ClearFlag(TIM1, TIM_IT_CC1);
	// TIM_ITConfig(TIM1, TIM_IT_CC1, ENABLE);
        #if USE_TIM10_IRQ
	/* Enable the TIM1_IRQn Interrupt */
	NVIC_InitTypeDef nvic_s;
	nvic_s.NVIC_IRQChannel = TIM1_UP_TIM10_IRQn;
	// nvic_s.NVIC_IRQChannel = TIM1_CC_IRQn;
	nvic_s.NVIC_IRQChannelPreemptionPriority = 0;
	nvic_s.NVIC_IRQChannelSubPriority = 0;
	nvic_s.NVIC_IRQChannelCmd = ENABLE;
	NVIC_Init(&nvic_s);
	#endif

	TIM_Cmd(TIM1, ENABLE);
	// enable motor timer main output (the bridge signals)
	TIM_CtrlPWMOutputs(TIM1, ENABLE);
}



void EXTI9_5_IRQHandler(void)
{
        int s1 = EXTI_GetITStatus(EXTI_Line6); // W
	int s2 = EXTI_GetITStatus(EXTI_Line8); // U
	int s3 = EXTI_GetITStatus(EXTI_Line9); // V

	if (s1 || s2 || s3)
	{

		// Clear interrupt flags
		EXTI_ClearITPendingBit(EXTI_Line6);
		EXTI_ClearITPendingBit(EXTI_Line8);
		EXTI_ClearITPendingBit(EXTI_Line9);

		// Commutation
		// HallSensorsGetPosition();
		// commutate();

		if (g_bldc)
		{
			int hall_pos = bldc_read_hall_state(g_bldc);
			bldc_hall_update_position(g_bldc, hall_pos);
			bldc_commutate(g_bldc);
			int speed;
			if ((hall_pos & 1) && s1)
			{
			  speed = TIM_GetCounter(TIM3);
				// calc speed
			  if (TIM_GetITStatus(TIM3, TIM_IT_Update)) { 
			    speed = 65535;
			    TIM_ClearITPendingBit(TIM3, TIM_IT_Update);
			  }
				
				TIM_Cmd(TIM3, ENABLE);
				TIM_SetCounter(TIM3, 0);
				if( speed >= 0)
				{
					g_bldc->speed_raw_valid = 1;
					g_bldc->speed_raw = (int)(1000000ULL << 9) / speed;

					int err = g_bldc->speed_setpoint - g_bldc->speed_raw;

					g_bldc->pwm_duty = pi_update( &g_bldc->speed_pi, err );
				}
			}

			if (s1)
			  g_bldc->hall_pulses[0]++; //W
			if (s2)
			  g_bldc->hall_pulses[1]++; //U
			if (s3)
			  g_bldc->hall_pulses[2]++; //V
		}
	}
}
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

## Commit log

2023-02-04 Initial commit of Tom's code, STM32F4 libraries and some modifications
    [flash.cfg]
2023-02-05 Add flywheel plate design
    [flywheel-B_Cu.gbr, flywheel-B_Mask.gbr, flywheel-B_Paste.gbr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]
2023-02-05 Clarify flywheel plate description
2023-02-05 Comparator circuit diagram
2023-02-05 added mechanics files and mechanics page
    [Coil_plate.FCStd, Coil_shaft.FCStd, Nut_tripod.FCStd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]
2023-02-05 Add context in landing page
2023-02-05 added video in landing page
2023-02-11 No interrupts from timer
2023-02-12 Use printf from newlib nano
2023-02-26 Blog post on printf and scanf
